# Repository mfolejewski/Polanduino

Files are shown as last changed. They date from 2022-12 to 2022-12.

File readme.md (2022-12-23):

# Polanduino - Arduino from Poland (RP2040 board)

## Description
Polanduino is a Raspberry Pi RP2040 evaluation board with classic Arduino Uno form factor, which has features, as following:
- PCB dimensions: 68,58 x 53,34 mm,
- all 30 GPIO pins connected to the pin header (Arduino Uno standard with extra 8 GPIO pins),
- 2-layer PCB board,
- onboard: 8MB QSPI Flash (WSON8 package), 12MHz oscillator, PWR LED,
- RESET/BOOT switches,
- USB-C interface for power supply, debugging MCU and for flashing SPI memory,
- DC barrel jack for power supply (12VDC default) 
- fully open source project (OSHW).

Here you can find:
- \Manufacturing files: all the production files for PCB ordering and assembly at JLCPCB (Gerber files, Pick & Place, BOM, etc.)
- \source files: source files in Altium Designer format (KiCad: TBD)

## License
Project published as Open Source Hardware (OSHW) under CERN OHL v1.2 (Open Hardware Licence).



Project has been certified as Open Source Hardware by the Open Source Hardware Association (OSHWA).

UID is: PL000012

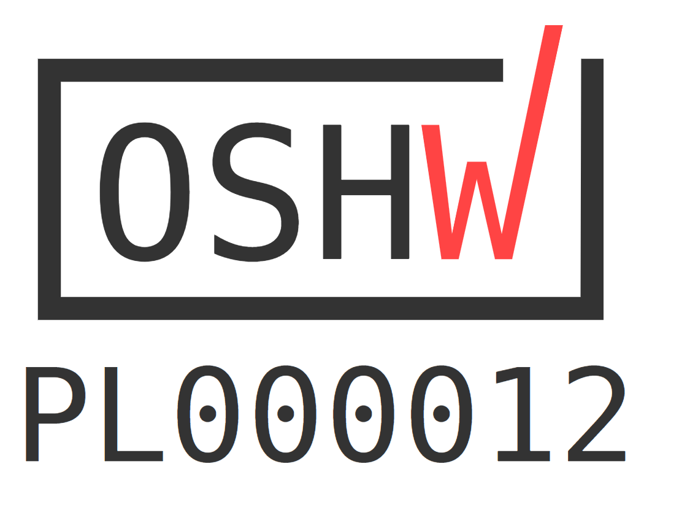
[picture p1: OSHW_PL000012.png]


https://certification.oshwa.org/pl000012.html

## Press release
TBD

## Photos
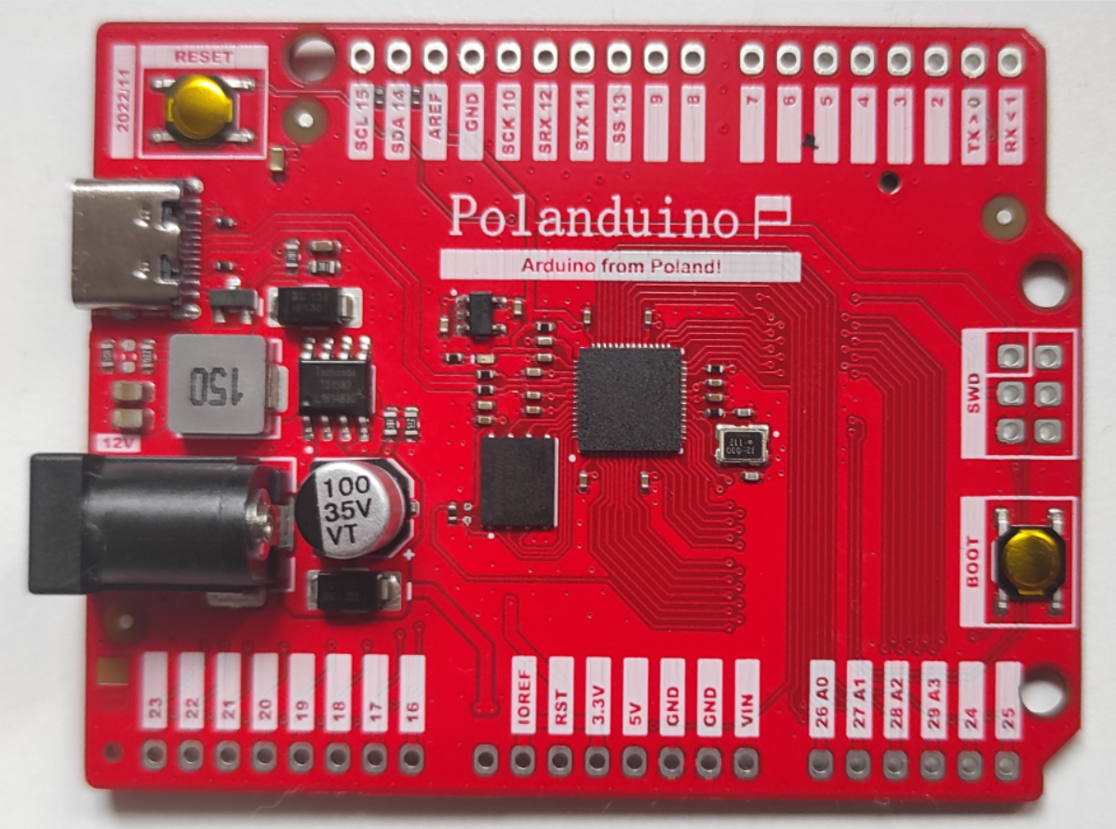
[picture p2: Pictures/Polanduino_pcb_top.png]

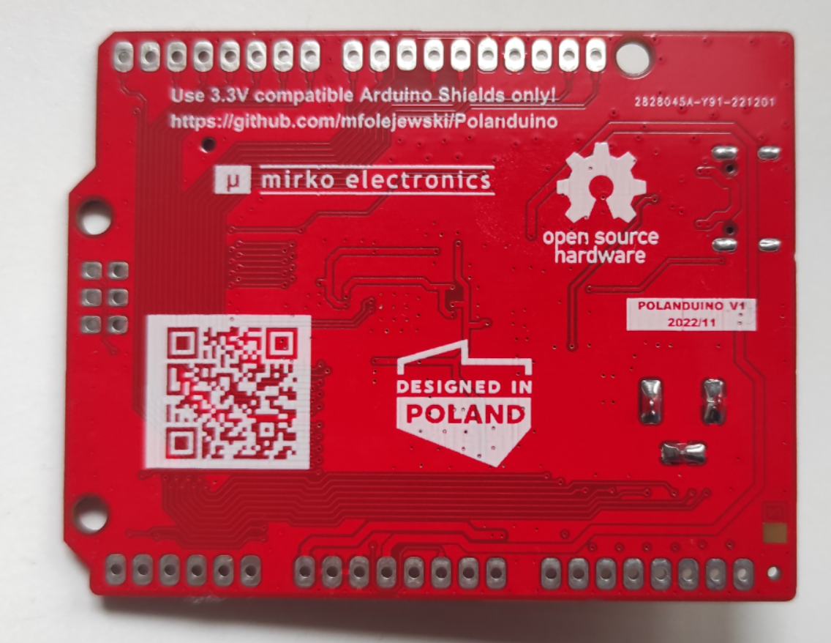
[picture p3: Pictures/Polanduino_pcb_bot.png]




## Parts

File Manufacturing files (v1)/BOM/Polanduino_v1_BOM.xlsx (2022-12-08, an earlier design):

Comment | Description | Designator | Footprint | LibRef | Quantity
2.2uF | Capacitor; MLCC; GENERIC; TBD; TBD; TBD; TBD; SMD; 0402 (1005); | C1, C2, C4, C15, C16, C17 | CAP_0402_R | CAP-0026 | 6
100nF | Capacitor; MLCC; GENERIC; TBD; TBD; TBD; TBD; SMD; 0402 (1005); | C3, C7, C8, C9, C10, C11, C12, C13, C14 | CAP_0402_R | CAP-0026 | 9
15pF | Capacitor; MLCC; GENERIC; TBD; TBD; TBD; TBD; SMD; 0402 (1005); | C5, C6 | CAP_0402_R | CAP-0026 | 2
47uF | Capacitor; MLCC; GENERIC; TBD; TBD; TBD; TBD; SMD; 0603 (1608); | C18 | CAP_0603_R | CAP-0023 | 1
22uF/16V | Capacitor; MLCC; GENERIC; TBD; TBD; TBD; TBD; SMD; 0805 (2012); | C501, C502 | CAP_0805_R | CAP-0024 | 2
DNP | Capacitor; MLCC; DNP; TBD; TBD; TBD; DO NOT PLACE; SMD; 0603 (1608); | C503 | CAP_0603_R | CAP-0018 | 1
100uF/35V | Capacitor; Polarized; | C504 | CAP_SMD_SIZE_D8 | CAP_POL_2P_NP | 1
100nF | Capacitor; MLCC; 100nF; TBD; TBD; TBD; TBD; SMD; 0603 (1608); | C776 | CAP_0603_R | CAP-0008 | 1
SS13 (1A/30V) | Diode; Schottky; Unipolar; | D500, D502 | DIO_SMA_UNI_R | DIO_TVS_UNI_KA | 2
U262-161N-4BVC11 | Connector; USB 3.1 Type C; Receptacle; 24-pin; USB 2.0 Only; | J33 | CON_XKB_U262-161N-4BVC11 | CON_USB_TYPE_C_16P | 1
5A, 2.0mm | Connector; DC Barrel Jack; | J92 | CON_WRT_694108301002 | CON_XKB_DC-005-5A-2.0 | 1
15uH | Inductor; | L500 | IND_SUM_0630CDMCCDS_700X660X280_R | IND | 1
Red | Diode; LED; Red; | LED26 | LED_0402_R | DIO_LED_RED | 1
PMOS | Transistor; PMOS; | Q900 | PKG_SOT23-3_TO236 | TRA_PMOS_GSD | 1
27R | Resistor; Thick Film; GENERIC; TBD; TBD; TBD; TBD; TBD; SMD; 0402 (1005); | R1, R2 | RES_0402_R | RES-0058 | 2
10k | Resistor; Thick Film; 10k; 1%; 62.5mW; 100PPM; 50V; Standard; SMD; 0402 (1005); | R3 | RES_0402_R | RES-0004 | 1
DNP | Resistor; Thick Film; GENERIC; TBD; TBD; TBD; TBD; TBD; SMD; 0402 (1005); | R4 | RES_0402_R | RES-0058 | 1
1k | Resistor; Thick Film; 1k; 1%; 62.5mW; 100PPM; 50V; Standard; SMD; 0402 (1005); | R5, R6 | RES_0402_R | RES-0003 | 2
100R | Resistor; Thick Film; 100R; 1%; 62.5mW; 100PPM; 50V; Standard; SMD; 0402 (1005); | R7 | RES_0402_R | RES-0002 | 1
5.1k | Resistor; Thick Film; GENERIC; TBD; TBD; TBD; TBD; TBD; SMD; 0402 (1005); | R8, R9 | RES_0402_R | RES-0058 | 2
2k | Resistor; Thick Film; GENERIC; TBD; TBD; TBD; TBD; TBD; SMD; 0402 (1005); | R33 | RES_0402_R | RES-0058 | 1
4.7k | Resistor; Thick Film; 4.7k; 1%; 62.5mW; 100PPM; 50V; Standard; SMD; 0402 (1005); | R37, R38 | RES_0402_R | RES-0019 | 2
6.2k | Resistor; Thick Film; GENERIC; TBD; TBD; TBD; TBD; TBD; SMD; 0603 (1608); | R502 | RES_0603_R | RES-0054 | 1
2k | Resistor; Thick Film; 2k2; 1%; 100mW; 100PPM; 75V; Standard; SMD; 0603 (1608); | R503 | RES_0603_R | RES-0033 | 1
15k | Resistor; Thick Film; 15k; 1%; 100mW; 100PPM; 75V; Standard; SMD; 0603 (1608); | R504, R511, R512 | RES_0603_R | RES-0043 | 3
5k1 | Resistor; Thick Film; 5k1; 1%; 100mW; 100PPM; 75V; Standard; SMD; 0603 (1608); | R505 | RES_0603_R | RES-0043 | 1
TACT Switch | Switch; Tactile; Monostable; | SW1, SW2 | SWI_C&K_PTS526SX08 | SWI_TACT_4P_AABB | 2
RP2040 | IC; MCU; | U1 | ICC_QFN56_700X700X90_P40_EP_RP2040 | ICC_RPI_RP2040_QFN56 | 1
W25Q64JV | ICC | U2 | ICC_WSON8_500X600X80P127_EP | ICC_WBD_W25Q64_SOIC_WSON | 1
NCP114ASN330T1G | ICC; LDO; | U3 | ICC_TSOT-5_290X160H110_P95 | ICC_ONS_NCP114_TSOP5 | 1
TD1583 | IC; Buck regulator; | U502 | ICC_SO8_SOP8_490X390X160_P127_R | ICC_TCH_TD1583_SOP8 | 1
12.000MHz | Oscillator; Crystal; | X1 | OSC_3225_4P_R | OSC_XTL_P4 | 1

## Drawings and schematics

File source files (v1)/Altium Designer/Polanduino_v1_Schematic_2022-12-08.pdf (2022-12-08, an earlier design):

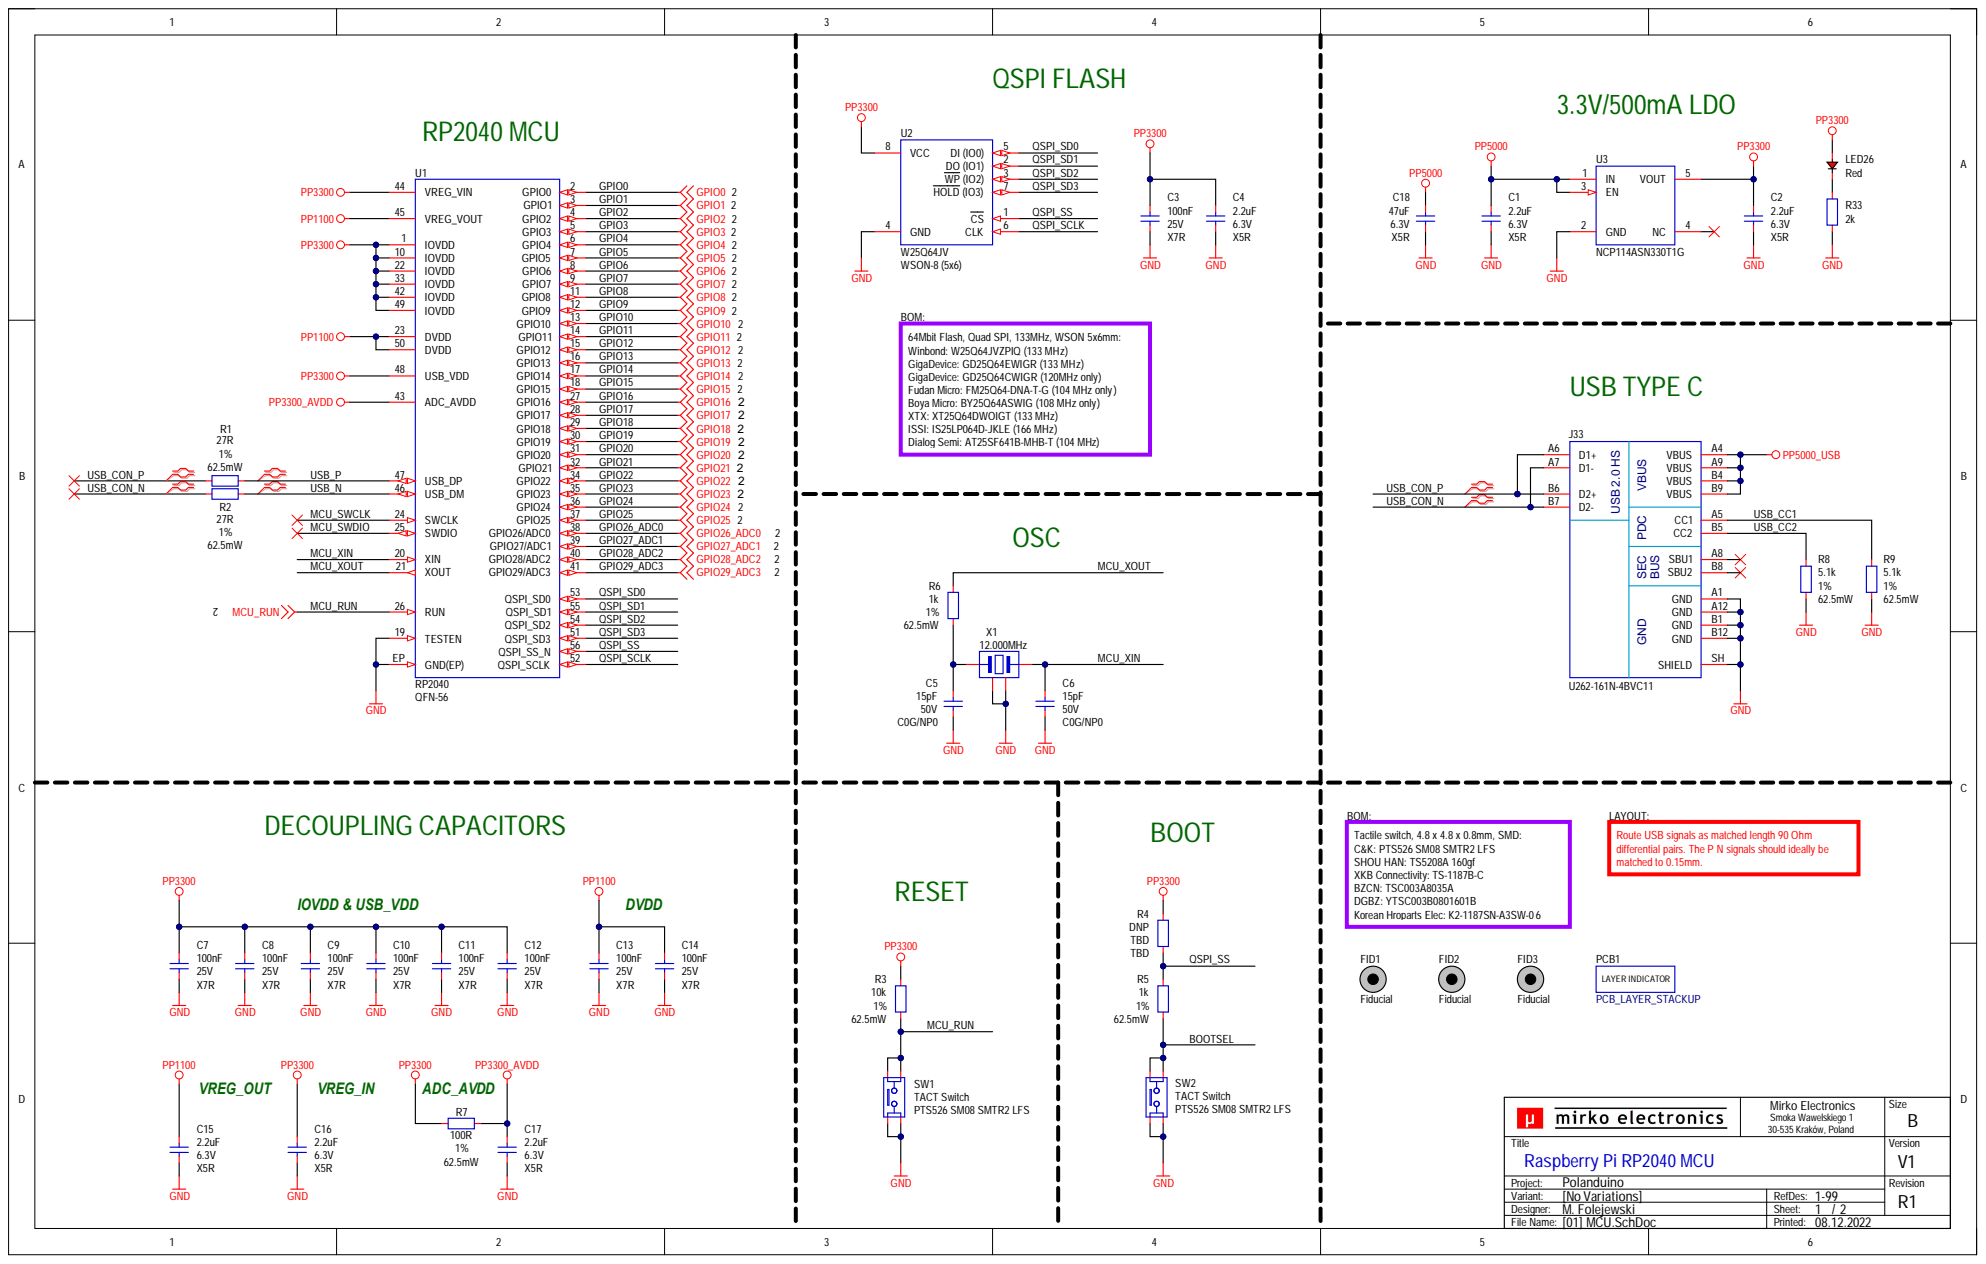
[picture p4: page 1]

OVDD 33
OVDD 42

D1+ A6 | VBUS

GND VBUS PDC SEC

GND(EP) EP QFN-56

rs. The P N signals should

Mirko Electronics Smoka Wawel ski ego 1 30-535 Kra kó w, Pol a nd | Size B

Ti tl e Ra spberry Pi RP 2040 MCU | | Version V 1

Project: Polanduino | | Revision R1
Variant: [No Variations] | RefDes: 1-99
Designer: M. Folejewski | Sheet:
Fi le Name: [01] MCU.SchDoc | Printed:

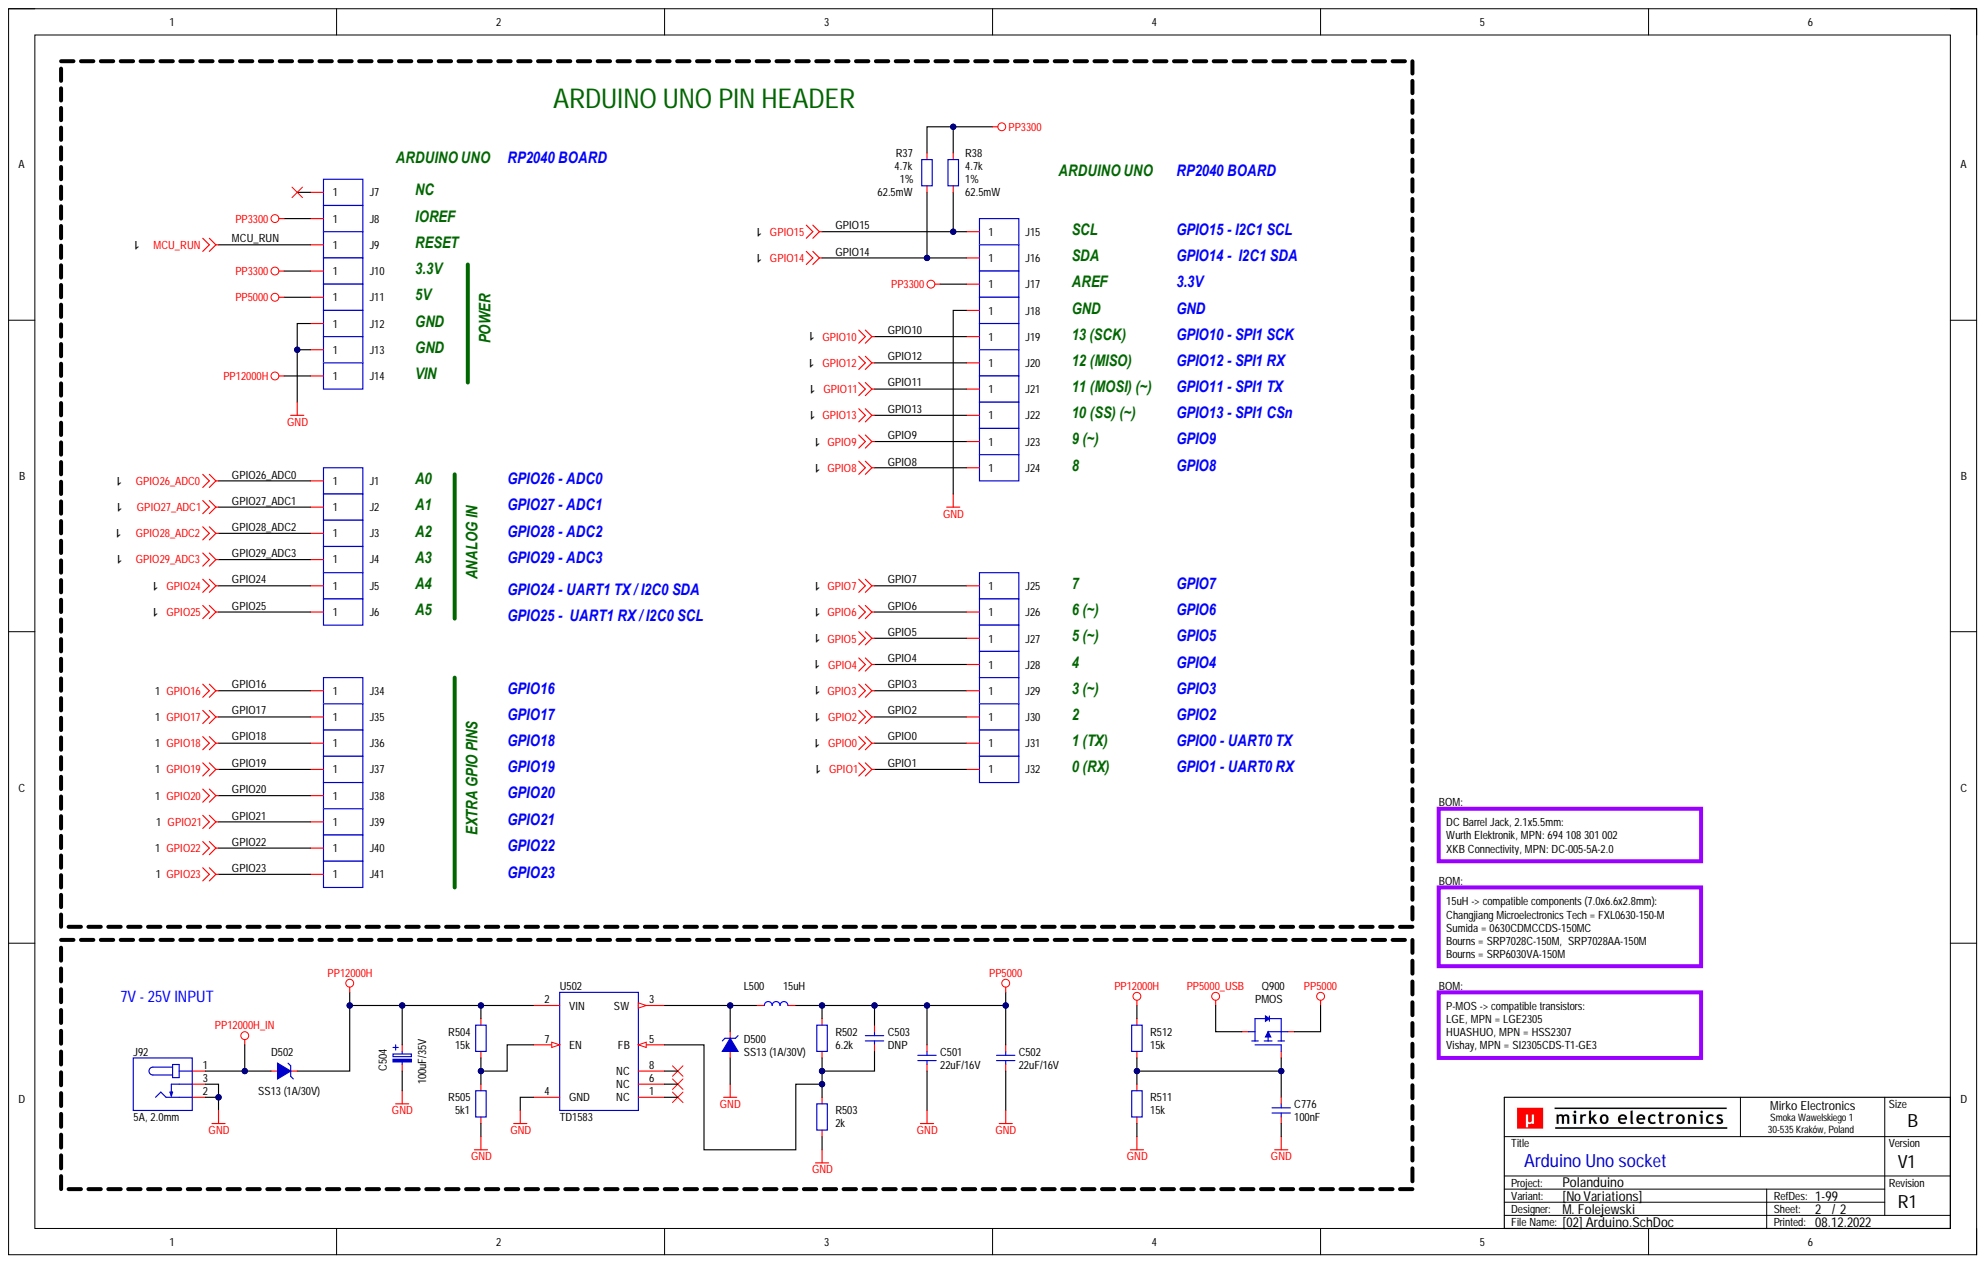
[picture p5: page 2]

ARDUINO UNO PIN HEADER

DC Barrel Jack, 2.1x5.5mm: Wurth Elektronik, MPN: 694 108 301 002

Ti tl e Arduino Uno soc ke t | Version V 1

Project: Polanduino | Revision R1
Variant: [No Variations] | RefDes: 1-99
Designer: M. Folejewski | Sheet:
Fi le Name: [02] Arduino.SchDoc | Printed:
